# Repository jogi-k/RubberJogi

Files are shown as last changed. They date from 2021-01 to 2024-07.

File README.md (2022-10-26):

# 	RubberJogi

## What is the idea / the usecase ?

* You want to control a PC from another PC, making keystrokes, eventually mouse-moves.
* Even when starting up and e.g. entering the BIOS 
* => ssh etc not an option
* you need to be independent from any "client" on the controlled machine
* only solution which comes to mind is : USB HID
* Therefore you connect from PC I somehow to PC II, on PC II as USB-Keyboard

## Solution : RubberJogi

    +----------------+                                  +----------------+
    |                |                                  |                |
    |    PC I        |                                  |    PC II       |
    |                |          +-------------+         |                |
    |  (Controller)  | USB      |             |  USB    |  (Worker)      |
    |                +--------->+ RubberJogi  +-------->+                |
    |                | serial   |             |  HID    |                |
    |                |          +-------------+         |                |
    |                |                                  |                |
    +----------------+                                  +----------------+

* PC I connects to RubberJogi via USB-Serial
* RubberJogi injects Keystrokes etc via USB HID to PC II 

## Ingredients Hardware

* Arduino ( with USB-Keyboard capability), e.g. Leonardo, Micro, etc

* USB-TTL UART Converter , FTDI Serial

* some cables

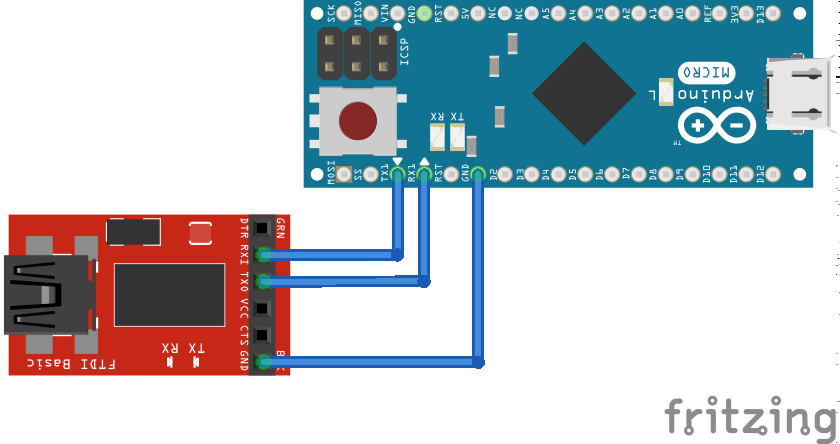
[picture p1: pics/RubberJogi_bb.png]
RubberJogi_bb
  

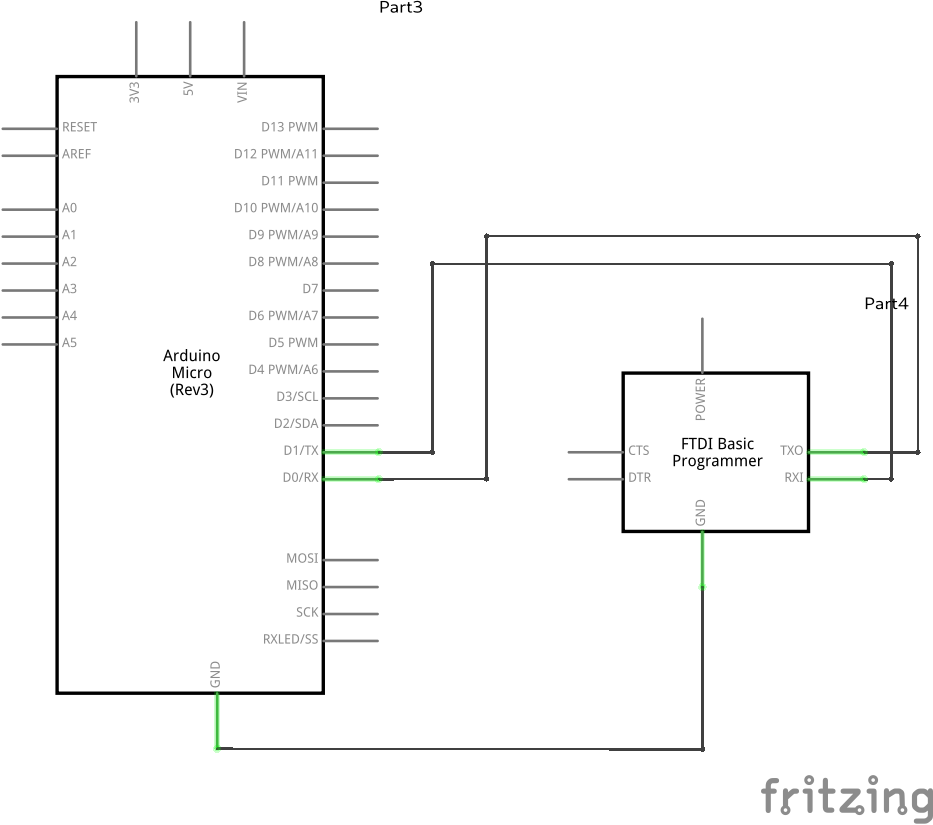
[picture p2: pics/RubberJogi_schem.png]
RubberJogi_schem
  

## Ingredients Software 

* As it is not possible to send CMD-Keys like ALT, CTRL via serial line, a language has to be used.
* Avoid to reinvent the wheel ==> Compatible to the famous [**RubberDucky**-Script-Language](https://github.com/hak5darren/USB-Rubber-Ducky/wiki/Duckyscript)
* ==> Based on arducky by Baptiste MOINE (Creased), THANKS!
* Parser is based on https://github.com/Creased/arducky/blob/master/arducky.ino
* is partially extended for also sending MOUSE-Movements
* is already extended to control four additional GPIO-Switches 
* Accepted Commands :
    * All RubberDucky-Commands (not really all...)
    * ```backspace```
    * ```switch1_on``` / ```switch1_off```  => switching Optocoupler at Pin2 
    * ```switch2_on``` / ```switch2_off```  => switching Optocoupler at Pin4 
    * ```switch3_on``` / ```switch3_off```  => switching Optocoupler at Pin6 
    * ```switch4_on``` / ```switch4_off```  => switching Optocoupler at Pin8
    * ```boot``` => switching Optocoupler at Pin2 for 1.5 sec high, then low
    * ```reboot``` => switching Optocoupler at Pin2 for 10sec high, then low, after a delay of 2 secs then once more for 1.5 sec high, then low
    * ```aten``` => switching Optocoupler at Pin4 for 1.5 sec high, then low

### Controlling 

For "talking" to the RubberJogi from PC1 you need to configure your serial port to

* 9600 Baud
* 8 Bit, 1 Stop-Bit, No parity

If you are using a linux-box you could use the follwing command to achieve this:   

```stty -F /dev/ttyUSB0 cs8 9600 ignbrk -brkint -icrnl -imaxbel -opost -onlcr -isig -icanon -iexten -echo -echoe -echok -echoctl -echoke noflsh -ixon -crtscts```  
Then you can just try out the functionality of the box with e.g :

* ```echo "ENTER" > /dev/ttyUSB0``` when you are allowed to use /dev/ttyUSB, or
* ```echo "ENTER" | sudo tee /dev/ttyUSB0``` when you need to be root to use /dev/ttyUSB

In both cases you should see a moving text-cursor on the second PC (best open an Editor...)

## Special Hardware with 2 switches

* In our/my usecase we also need to control two switches

* one of these is connected to the reset-button of the PC

* the other one is connected to the switch of a USB-sharing station, so we can switch a USB-stick between PC1 and PC2 ...

* more explanations will follow, the code is already able to make use of these 

* here at least are the schematics

* In case you want (like we do) to switch on PC2 with a command from PC1 you need to connect Vcc between FTDI and Arduino, otherwise the Arduino will not have power when he is connected to a switched of PC ... ( see the green cable below)
* Unfortunately, it looks like this is backfeeding 5V even to the 2nd PC via USB. This is not a problem if the PC is switched on. __BUT__ : If you have the PC switched off and want to switch it on, then - depending on the PC - it might make some trouble for the PC, as it is never __really__ switching completely off. I need to try this remedy : https://forum.arduino.cc/t/powering-the-arduino-with-a-5v-power-supply/261902/12   

* We tried out this remedy (remove T1 of the ARDUINO) and it works perfect. __BUT beware:__ when you want to re-programm the Arduino you __NEED__ to have the FTDI connected as well to a PC, as otherwise the Arduino is not powered...
* See here the location of the T1 to be removed: 
![Arduino T1 to be removed](pics/Arduino_T1_to_remove.png)

  ![RubberJogi_with_switch_bb](pics/RubberJogi_with_switch_bb.png)

  ![RubberJogi_with_switch_schem](pics/RubberJogi_with_switch_schem.png)

## Extended Special Hardware with 4 switches

  - in the meantime we even have use-cases where we need to control up to 4 switches

  - as before one of these is connected to the reset-button of the PC (in our case)

  - as before one is connected to the switch of a USB-sharing station, so we can switch a USB-stick between PC1 and PC2 ... (in our case)

  - the other 2 switches are needed to control boot-sel switches of embedded ARM systems  

  - here are the additional schematics

  - In case you want (like we do) to switch on PC2 with a command from PC1 you need to connect Vcc between FTDI and Arduino, otherwise the Arduino will not have power when he is connected to a switched of PC ... ( see the green cable below)
  - backfeeding 5V via USB to PC2: see above at the 2-Switch-Solution)

    ![RubberJogi_with_switch_bb](pics/RubberJogi_with_4_switches_bb.png)

    ![RubberJogi_with_switch_schem](pics/RubberJogi_with_4_switches_schem.png)

## Extended Special Hardware with 5 switches and one relay

- finally (in our application) we need to switch power 
- we introduced a 5th optocoupler, connected to pin10 AND we connected a real relay to that to be able to switch power
- schematics will follow

## Reality

This is one sample-prototype without any switches, just the "plain" RubberJogi. This was soldered "flying" and is only stabilized with heat shrink tube.

![RubberJogi_with_4_switches_sample](pics/RubberJogi_Aufbau_NoSwitch.jpg)

This is one sample-prototype, with 4 switches, soldered on a veroboard/breadboard

![RubberJogi_with_4_switches_sample](pics/RubberJogi_Aufbau.jpg)

These are all 3 prototypes I have built, together on one picture. 

* 2 times extended RubberJogis with 4 switches
* 1 as a pure RubberJogi, no switches.

![Different RubberJogis](pics/RubberJogi_all.jpg)

## Parts-List

What do you need to build a RubberJogi?

| Part                                                  | Rubber<br> Jogi<br> Standard | Rubber <br> Jogi<br>Two Switch | Rubber <br> Jogi<br>Four Switch |
| ----------------------------------------------------- | ---------------------------- | ------------------------------ | ------------------------------- |
| Arduino Micro                                         | 1                            | 1                              | 1                               |
| FTDI USB / Serial Converter 5V capable                | 1                            | 1                              | 1                               |
| Cables between Arduino/FTDI<br>(Vcc, GND, RxD, TxD)   | 4                            | 4                              | 4                               |
| USB-Cable to Arduino <br />(USB-A to Micro-USB)       | 1                            | 1                              | 1                               |
| USB-Cable to FTDI<br>(USB-A to Mini-USB)              | 1                            | 1                              | 1                               |
| Veroboard                                             | ?                            | ca 60x50 mm                    | ca 60x50mm                      |
| Header Arduino<br>(when not using already w/ headers) | ?                            | 34                             | 34                              |
| Header FTDI                                           | ?                            | 18                             | 18                              |
| Optocoupler 4N25 DIL                                  | 0                            | 2                              | 4                               |
| Resistor 390 Ohm                                      | 0                            | 2                              | 4                               |
| Connectors, depends on your needs, e.g                | 0                            | 2                              | 4                               |
| **Example**: Headers for switches                     | 0                            | 4                              | 8                               |

## Links, Ideas

* Mouse-Support currently missing to 90%, positioning does not work. Maybe move to USB-Touch-Screen could solve the problem? Please have a look at this project, might be worth checking out : https://github.com/NicoHood/HID
* Another potential usefull link to solve the mouse-move would be  : https://www.codeproject.com/Articles/1001891/A-USB-HID-Keyboard-Mouse-Touchscreen-emulator-with

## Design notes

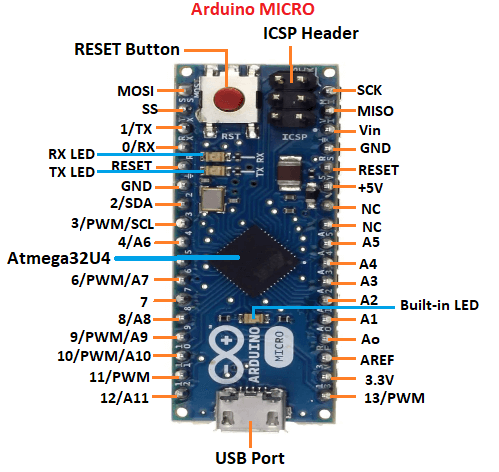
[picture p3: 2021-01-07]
arduino-micro-pinout.png

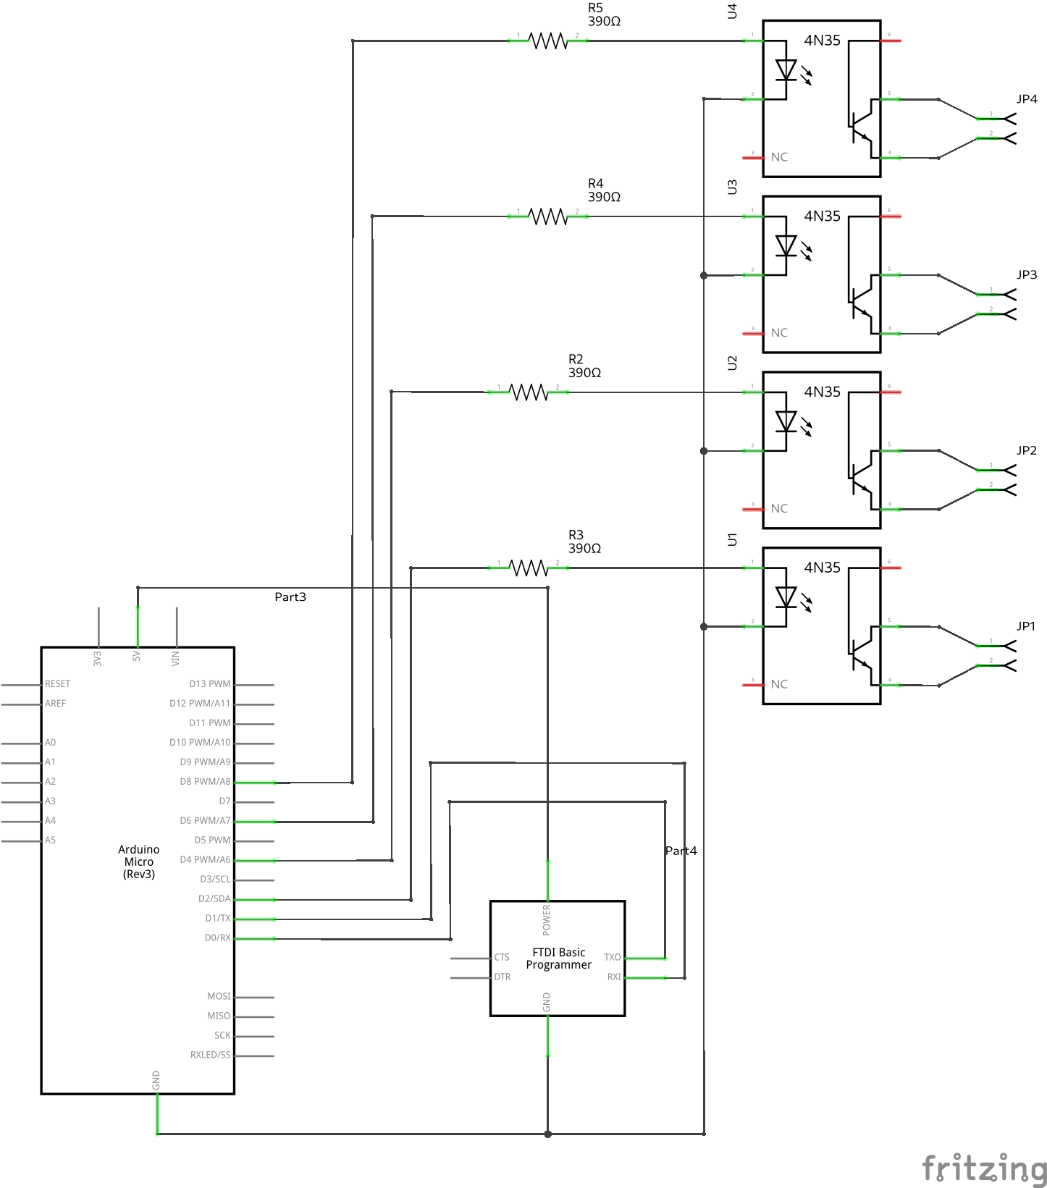
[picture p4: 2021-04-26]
pics/RubberJogi_with_4_switches_schem.png

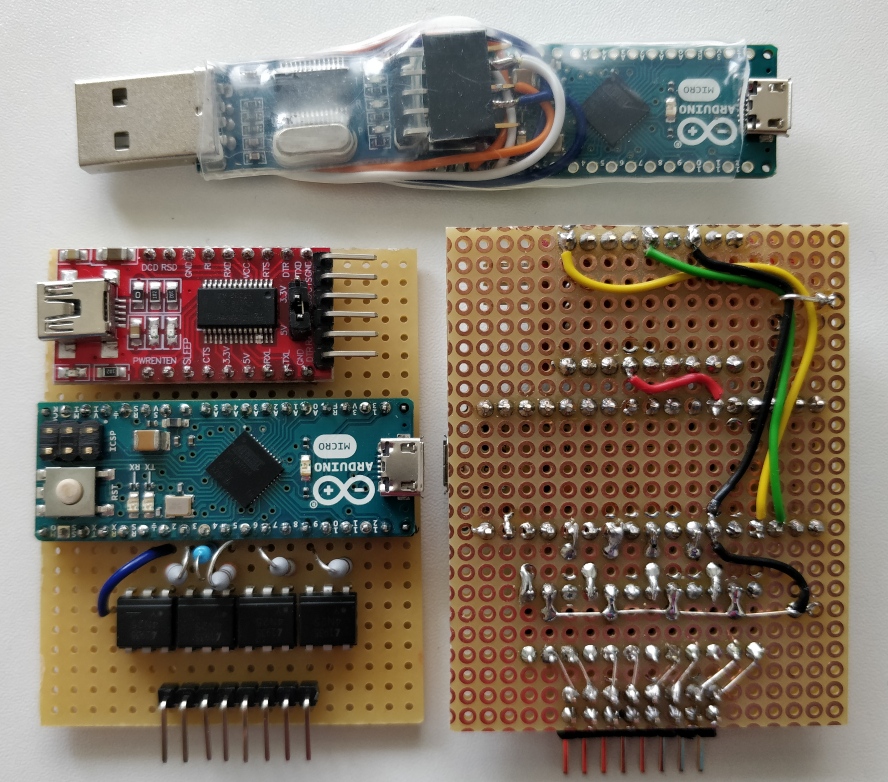
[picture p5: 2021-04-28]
pics/RubberJogi_all.jpg

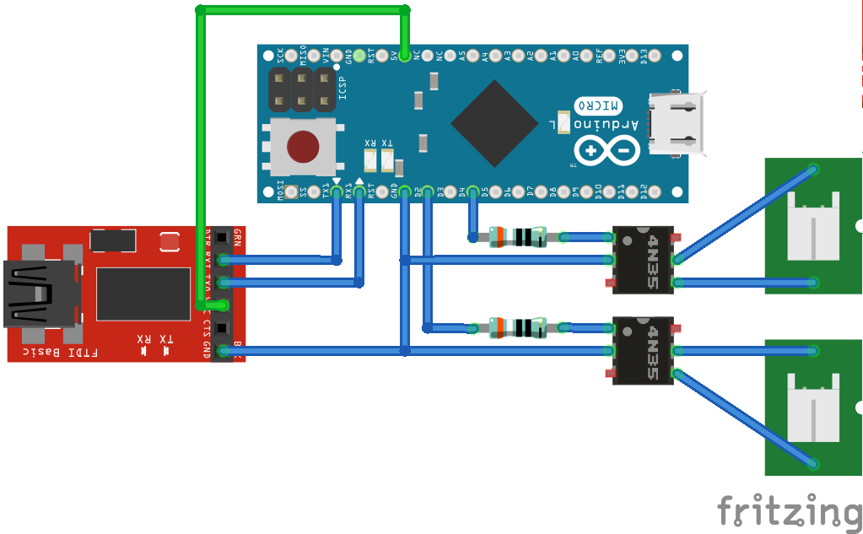
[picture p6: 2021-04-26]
pics/RubberJogi_with_switch_bb.png

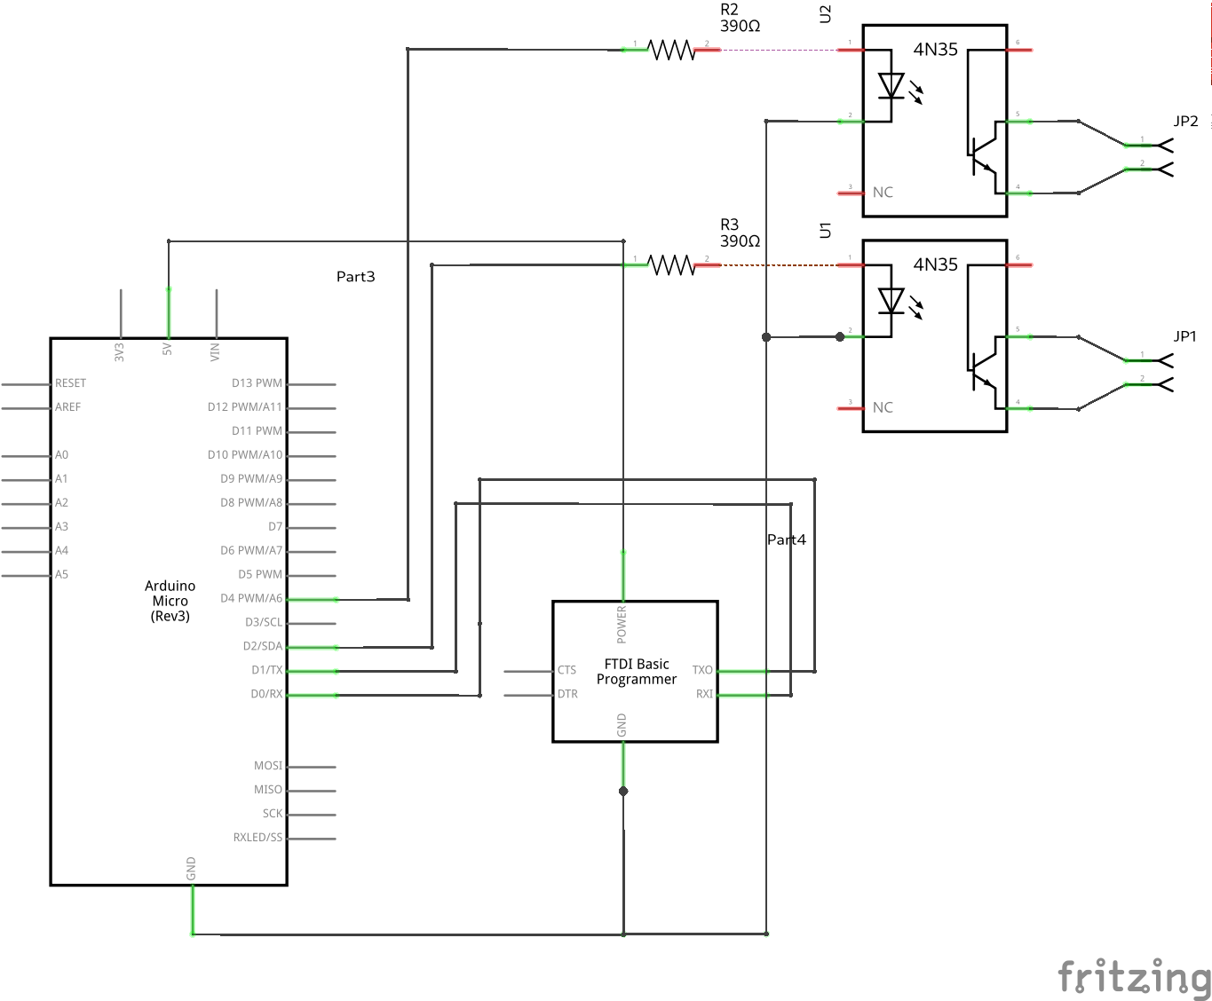
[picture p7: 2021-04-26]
pics/RubberJogi_with_switch_schem.png

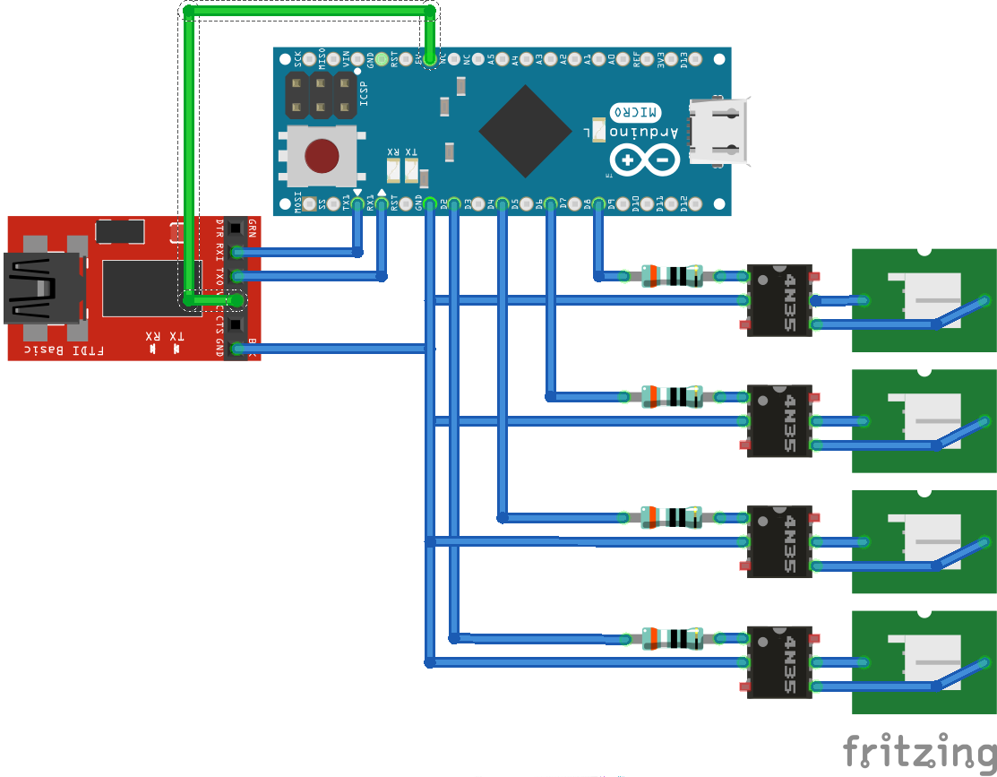
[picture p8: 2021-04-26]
pics/RubberJogi_with_4_switches_bb.png

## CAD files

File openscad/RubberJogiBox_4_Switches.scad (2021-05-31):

$fn=100;




translate([-w/2-10,0,d+bpt+tpt])
rotate(a=180, v=[0,1,0])
box_top();
translate([w/2+10,0,0])
box_bottom();
             

//*************************************************//
//PARAMETERS
//*************************************************//
//BOX
//--------------------------------------------------
//inner box width + tolerances
w=80;
//inner box length + tolerances
h=50;
//inner box depth 
d=20;
//wall tickness
wt=3;
//bottom plate tickness
bpt=3;
//top plate tickness
tpt=3;
//top cutout depth
cd=3;
//top cutout tickness
cwt=1.5;
//--------------------------------------------------
//BOARD MOUNTING HOLES
//--------------------------------------------------
//position
cx=0;
cy=0;
//holes size (radius)
chs_i=1.5;
chs_o=4;
//distancer height
dsth=3;
//holes distance h
chd_h=65;
//holes distance v
chd_v=35;
//--------------------------------------------------
//TOP PART MOUNTING HOLES
//--------------------------------------------------
//position
cx1=0;
cy1=0;
//holes size (radius)
chs_i1=1.6;
chs_o1=3;
//holes distance h
chd_h1=h-2*chs_i1-2;
//holes distance v
chd_v1=w-2*chs_i1-2;
//*************************************************//
//*************************************************//
//MODULES
//*************************************************//

//top box part          
module box_top()
{
        difference()
        {
            union()
            {
                difference()
                {
                    translate([ 0, 0, d+bpt-cd-0.2])     
                    rounded_cube( w+2*wt, h+2*wt, tpt+cd+0.2, 6);
                    
                    translate([ 0, 0,  d+bpt-cd-1])
                    rounded_cube( w+2*cwt+0.3, h+2*cwt+0.3, cd+1, 4);
                }
                /*************************/
                
                //add here...
                
                /*************************/
            }
            //TOP PART HOLES
            tph_t_cut();
            /*************************/
            
            //subtract here... 
            
            /*************************/ 
        }
}
//bottom box
module box_bottom()
{
    difference()
    {
        union()
        {
            difference()
            {
                rounded_cube( w+2*wt, h+2*wt, d+bpt, 6);
                
                translate([ 0, 0, -cd])
                difference()
                {
                    translate([ 0, 0,  d+bpt])
                    rounded_cube( w+2*wt+1, h+2*wt+1, cd+1, 4);

                    translate([ 0, 0,  d+bpt-1])
                    rounded_cube( w+2*cwt, h+2*cwt, cd+3, 4);
                }
                translate([ 0, 0, bpt])
                rounded_cube( w, h, d+bpt, 4);
            }
            //BOARD DISTANCER
            board_distancer();
            //TOP PLATE DISTANCER
            top_distancer();
            /*************************/
            
            //add here...
            
            /*************************/
        }
        
        //BOARD HOLES
        bh_cut();
        //TOP PART HOLES
        tph_b_cut();
        /*************************/
        
        //subtract here...
        
        /*************************/
  
    }
}

/****************************************************/
module board_distancer()
{
    translate([cx,cy,0])
    {              
        translate([+chd_h/2,chd_v/2,0])
        cylinder(r=chs_o,h=bpt+dsth);
        translate([-chd_h/2,chd_v/2,0])
        cylinder(r=chs_o,h=bpt+dsth);
        translate([+chd_h/2,-chd_v/2,0])
        cylinder(r=chs_o,h=bpt+dsth);
        translate([-chd_h/2,-chd_v/2,0])
        cylinder(r=chs_o,h=bpt+dsth);
    }
}
module top_distancer()
{
    translate([cx1,cy1,0])
    {
        translate([-chd_v1/2, chd_h1/2, 0])   
        cylinder(r=chs_o1,h=d+bpt);
        translate([-chd_v1/2, -chd_h1/2, 0])   
        cylinder(r=chs_o1,h=d+bpt);
        translate([chd_v1/2, chd_h1/2, 0])   
        cylinder(r=chs_o1,h=d+bpt);
        translate([chd_v1/2, -chd_h1/2, 0])   
        cylinder(r=chs_o1,h=d+bpt);
    }
}
module bh_cut()
{
    translate([cx,cy,0])
    {  
        translate([-chd_h/2,-chd_v/2,-1])
        cylinder(r=chs_i,h=bpt+dsth+2);
        translate([+chd_h/2,-chd_v/2,-1])
        cylinder(r=chs_i,h=bpt+dsth+2);
        translate([-chd_h/2,chd_v/2,-1])
        cylinder(r=chs_i,h=bpt+dsth+2);
        translate([+chd_h/2,chd_v/2,-1])
        cylinder(r=chs_i,h=bpt+dsth+2);
        
        translate([-chd_h/2,-chd_v/2,1.3])
        fhex(5.5,3);
        translate([+chd_h/2,-chd_v/2,1.3])
        fhex(5.5,3);
        translate([-chd_h/2,chd_v/2,1.3])
        fhex(5.5,3);
        translate([+chd_h/2,chd_v/2,1.3])
        fhex(5.5,3);
    }
}

module tph_t_cut()
{
    translate([cx1,cy1,0])
    {
        translate([-chd_v1/2, chd_h1/2, -2])   
        cylinder(r=chs_i1,h=d+bpt+tpt+3);
        translate([chd_v1/2, chd_h1/2, -2])   
        cylinder(r=chs_i1,h=d+bpt+tpt+3);
    
        translate([-chd_v1/2, -chd_h1/2, -2])   
        cylinder(r=chs_i1,h=d+bpt+tpt+3);
        translate([chd_v1/2, -chd_h1/2, -2])   
        cylinder(r=chs_i1,h=d+bpt+tpt+3);
        
        translate([-chd_v1/2, chd_h1/2, d+bpt+tpt-1.3]) 
        fhex(5.5,3);
        
        translate([chd_v1/2, chd_h1/2, d+bpt+tpt-1.3])  
        fhex(5.5,3);
    
        translate([-chd_v1/2, -chd_h1/2, d+bpt+tpt-1.3])   
        fhex(5.5,3);
        
        translate([chd_v1/2, -chd_h1/2, d+bpt+tpt-1.3])   
        fhex(5.5,3);
    
    }   
}
module tph_b_cut()
{
    translate([cx1,cy1,0])
    {
        translate([-chd_v1/2, chd_h1/2, -2])   
        cylinder(r=chs_i1,h=d+bpt+3);
        translate([chd_v1/2, chd_h1/2, -2])   
        cylinder(r=chs_i1,h=d+bpt+3);
    
        translate([-chd_v1/2, -chd_h1/2, -2])   
        cylinder(r=chs_i1,h=d+bpt+3);
        translate([chd_v1/2, -chd_h1/2, -2])   
        cylinder(r=chs_i1,h=d+bpt+3);
        
        translate([-chd_v1/2, chd_h1/2, -1]) 
        cylinder(r=3,h=4);
        
        translate([chd_v1/2, chd_h1/2, -1])  
        cylinder(r=3,h=4);
    
        translate([-chd_v1/2, -chd_h1/2, -1])   
        cylinder(r=3,h=4);
        
        translate([chd_v1/2, -chd_h1/2, -1])   
        cylinder(r=3,h=4); 
    
    }   
}


module rounded_cube( x, y, z, r)
{
    translate([-x/2+r,-y/2+r,0])
    linear_extrude(height=z)
    minkowski() 
    {
        square([x-2*r,y-2*r],true);
        translate([x/2-r,y/2-r,0])
        circle(r);

    }
}

module fhex(wid,height)
{
    hull()
    {
        cube([wid/1.7,wid,height],center = true);
        rotate([0,0,120])cube([wid/1.7,wid,height],center = true);
        rotate([0,0,240])cube([wid/1.7,wid,height],center = true);
    }
}

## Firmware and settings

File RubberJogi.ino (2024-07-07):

// RubberJogi
// ==========
//
// Use it like its name-patron the RubberDucky, but:
// Instead of reading the RubberDucky-Script from SD-card, RubberJogi receives
// its commands from the Controller-PC
//
// Receives Data on the serial1 (NOT USB-serial), parses it according to
// RubberDucky-Language-definition and "executes" then on the USB-HID , keyboard
// and mouse. Use together with an USB TTL UART - connector to control a PC with
// a simulated keyboard.
//
// Thanks very much to Baptiste M. (Creased) , who created arducky (
// https://github.com/Creased/arducky ) from where I have taken 90% of the base
// of this tool,

#include "RubberJogi.h"

RubberJogi rj;

void setup() { rj.printVersion(); }

void loop() {
  if (rj.readCommand()) {
    rj.parseCommand();
  }
}

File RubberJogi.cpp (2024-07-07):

#include "RubberJogi.h"

#include "Keys.h"

namespace {
enum MouseButtons : uint8_t {
  LEFT = 1,
  RIGHT = 2,
  MIDDLE = 4,
};

bool isKeyboardCommand(String cmd) {
  cmd.toUpperCase();
  return cmd == "ENTER" || cmd == "DOWNARROW" || cmd == "DOWN" ||
         cmd == "LEFTARROW" || cmd == "LEFT" || cmd == "RIGHTARROW" ||
         cmd == "RIGHT" || cmd == "UPARROW" || cmd == "UP" || cmd == "DELETE" ||
         cmd == "DEL" || cmd == "END" || cmd == "ESC" || cmd == "ESCAPE" ||
         cmd == "HOME" || cmd == "INSERT" || cmd == "PAGEUP" ||
         cmd == "PAGEDOWN" || cmd == "PRINTSCREEN" || cmd == "SPACE" ||
         cmd == "TAB" || cmd == "F1" || cmd == "F2" || cmd == "F3" ||
         cmd == "F4" || cmd == "F5" || cmd == "F6" || cmd == "F7" ||
         cmd == "F8" || cmd == "F9" || cmd == "F10" || cmd == "F11" ||
         cmd == "F12" || cmd == "FUNCTION1" || cmd == "FUNCTION2" ||
         cmd == "FUNCTION3" || cmd == "FUNCTION4" || cmd == "FUNCTION5" ||
         cmd == "FUNCTION6" || cmd == "FUNCTION7" || cmd == "FUNCTION8" ||
         cmd == "FUNCTION9" || cmd == "FUNCTION10" || cmd == "FUNCTION11" ||
         cmd == "FUNCTION12" || cmd == "BACKSPACE" || cmd == "CAPSLOCK" ||
         cmd == "SCROLLLOCK" || cmd == "NUMLOCK" || cmd == "MENU" ||
         cmd == "APP" || cmd == "PAUSE" || cmd == "BREAK" ||
         cmd.startsWith("SHIFT") || cmd.startsWith("ALT") ||
         cmd.startsWith("CTRL") || cmd.startsWith("CONTROL") ||
         cmd.startsWith("GUI") || cmd.startsWith("WINDOWS") ||
         cmd.startsWith("STRING ") || cmd.startsWith("INJECT_MOD ");
}

bool isMouseCommand(const String &cmd) {
  return cmd.substring(0, 5).equalsIgnoreCase("MOUSE");
}

bool isSwitchCommand(String cmd) {
  cmd.toUpperCase();
  return cmd.startsWith("SWITCH") || cmd == "BOOT" || cmd == "REBOOT" ||
         cmd == "ATEN";
}

bool isDelayCommand(const String &cmd) {
  return cmd.substring(0, 5).equalsIgnoreCase("DELAY");
}

bool isComment(const String &cmd) { return cmd.equalsIgnoreCase("REM"); }

uint8_t getKeyCode(const String &key) {
  if (key.length() == 1) {
    return key[0];
  } else if (key.equalsIgnoreCase("ENTER")) {
    return KEY_RETURN;
  } else if (key.equalsIgnoreCase("MENU") || key.equalsIgnoreCase("APP")) {
    return KEY_MENU;
  } else if (key.equalsIgnoreCase("DOWNARROW") ||
             key.equalsIgnoreCase("DOWN")) {
    return KEY_DOWN_ARROW;
  } else if (key.equalsIgnoreCase("LEFTARROW") ||
             key.equalsIgnoreCase("LEFT")) {
    return KEY_LEFT_ARROW;
  } else if (key.equalsIgnoreCase("RIGHTARROW") ||
             key.equalsIgnoreCase("RIGHT")) {
    return KEY_RIGHT_ARROW;
  } else if (key.equalsIgnoreCase("UPARROW") || key.equalsIgnoreCase("UP")) {
    return KEY_UP_ARROW;
  } else if (key.equalsIgnoreCase("PAUSE") || key.equalsIgnoreCase("BREAK")) {
    return KEY_PAUSE;
  } else if (key.equalsIgnoreCase("CAPSLOCK")) {
    return KEY_CAPS_LOCK;
  } else if (key.equalsIgnoreCase("DELETE") || key.equalsIgnoreCase("DEL")) {
    return KEY_DELETE;
  } else if (key.equalsIgnoreCase("END")) {
    return KEY_END;
  } else if (key.equalsIgnoreCase("ESC") || key.equalsIgnoreCase("ESCAPE")) {
    return KEY_ESC;
  } else if (key.equalsIgnoreCase("HOME")) {
    return KEY_HOME;
  } else if (key.equalsIgnoreCase("INSERT")) {
    return KEY_INSERT;
  } else if (key.equalsIgnoreCase("NUMLOCK")) {
    return KEY_NUM_LOCK;
  } else if (key.equalsIgnoreCase("PAGEUP")) {
    return KEY_PAGE_UP;
  } else if (key.equalsIgnoreCase("PAGEDOWN")) {
    return KEY_PAGE_DOWN;
  } else if (key.equalsIgnoreCase("PRINTSCREEN")) {
    return KEY_PRINT_SCREEN;
  } else if (key.equalsIgnoreCase("SCROLLLOCK")) {
    return KEY_SCROLL_LOCK;
  } else if (key.equalsIgnoreCase("SPACE")) {
    return KEY_SPACE;
  } else if (key.equalsIgnoreCase("BACKSPACE")) {
    return KEY_BACKSPACE;
  } else if (key.equalsIgnoreCase("TAB")) {
    return KEY_TAB;
  } else if (key.equalsIgnoreCase("GUI") || key.equalsIgnoreCase("WINDOWS")) {
    return KEY_LEFT_GUI;
  } else if (key.equalsIgnoreCase("SHIFT")) {
    return KEY_RIGHT_SHIFT;
  } else if (key.equalsIgnoreCase("ALT")) {
    return KEY_LEFT_ALT;
  } else if (key.equalsIgnoreCase("CTRL") || key.equalsIgnoreCase("CONTROL")) {
    return KEY_LEFT_CTRL;
  } else if (key.equalsIgnoreCase("F1") || key.equalsIgnoreCase("FUNCTION1")) {
    return KEY_F1;
  } else if (key.equalsIgnoreCase("F2") || key.equalsIgnoreCase("FUNCTION2")) {
    return KEY_F2;
  } else if (key.equalsIgnoreCase("F3") || key.equalsIgnoreCase("FUNCTION3")) {
    return KEY_F3;
  } else if (key.equalsIgnoreCase("F4") || key.equalsIgnoreCase("FUNCTION4")) {
    return KEY_F4;
  } else if (key.equalsIgnoreCase("F5") || key.equalsIgnoreCase("FUNCTION5")) {
    return KEY_F5;
  } else if (key.equalsIgnoreCase("F6") || key.equalsIgnoreCase("FUNCTION6")) {
    return KEY_F6;
  } else if (key.equalsIgnoreCase("F7") || key.equalsIgnoreCase("FUNCTION7")) {
    return KEY_F7;
  } else if (key.equalsIgnoreCase("F8") || key.equalsIgnoreCase("FUNCTION8")) {
    return KEY_F8;
  } else if (key.equalsIgnoreCase("F9") || key.equalsIgnoreCase("FUNCTION9")) {
    return KEY_F9;
  } else if (key.equalsIgnoreCase("F10") ||
             key.equalsIgnoreCase("FUNCTION10")) {
    return KEY_F10;
  } else if (key.equalsIgnoreCase("F11") ||
             key.equalsIgnoreCase("FUNCTION11")) {
    return KEY_F11;
  } else if (key.equalsIgnoreCase("F12") ||
             key.equalsIgnoreCase("FUNCTION12")) {
    return KEY_F12;
  }

  return -1;
}

bool isModifierKey(uint8_t key) {
  switch (key) {
  case KEY_LEFT_SHIFT:
  case KEY_RIGHT_SHIFT:
  case KEY_LEFT_ALT:
  case KEY_RIGHT_ALT:
  case KEY_LEFT_CTRL:
  case KEY_RIGHT_CTRL:
  case KEY_LEFT_GUI:
  case KEY_RIGHT_GUI:
    return true;
  default:
    return false;
  }
}

} // namespace

RubberJogi::RubberJogi()
    : PluggableUSBModule(NUM_INTERFACES, NUM_ENDPOINTS, _epType) {
  Serial1.begin(9600);

  _buffer.reserve(100);

  static_assert(MOUSE_OFFSET < NUM_ENDPOINTS);

  _epType[KEYBOARD_OFFSET] = EP_TYPE_INTERRUPT_IN;
  _epType[MOUSE_OFFSET] = EP_TYPE_INTERRUPT_IN;

  PluggableUSB().plug(this);

  _initSwitches();
}

void RubberJogi::printVersion() const {
  Serial1.println(VERSION);
  Serial1.println("w BOOT/ATEN/SWITCH-Support");
}

void RubberJogi::setKeyboardLayout(const uint8_t *layout) { _layout = layout; }

bool RubberJogi::readCommand() {
  while (Serial1.available()) {
    char c = Serial1.read();

    // CR and LF terminate commands and are not added to the buffer
    // Don't report a new command being available if the buffer is empty
    if (c == '\r' || c == '\n') {
      if (_buffer.length() > 0) {
        Serial1.println(String("Received: ") + _buffer);
        return true;
      } else {
        continue;
      }
    }

    _buffer += c;
  }

  return false;
}

const String &RubberJogi::getCommand() const { return _buffer; }
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

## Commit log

2021-01-16 Improved documentation, added fritzing-files and pictures
    [RubberJogi.fzz]
2021-01-16 Added the two switches via Opto-Coupler as fritzing and in the README
    [RubberJogi_with_switch.fzz]
2021-01-17 First Mouse-Movements and support for ATEN-Switch (hijacked MOUSE_CENTER...)
2021-01-19 Support for the two Optocoupler-Switches (only with old commands), Support for GUI without payload
2021-01-19 Updated HW-Layout etc for RubberJogi with Switches, Port 3 => Port 4
    [RubberJogi_with_switch.fzz]
2021-04-17 Prepare for 4 Switches
    [RubberJogi_with_4_switches.fzz]
2021-04-18 Add 4 Switch functionality, rename some strings to distinguish between original and new
2021-04-25 RubberJogi with 4 instead of 2 switches
    [RubberJogi_with_4_switches.fzz]
2021-04-25 New pictures and move fritzing-files to subdir
    [RubberJogi.fzz, RubberJogi_with_4_switches.fzz, RubberJogi_with_switch.fzz]
2021-04-26 Added photos, some clarifications, added Vcc - Line and explanation
    [RubberJogi_with_4_switches.fzz, RubberJogi_with_switch.fzz]
2021-04-28 Fixed backspace-problem, Fixes #2
    [RubberJogi.ino]
2021-05-03 Added simplest test-shellscript for the switches
2021-05-31 Box with OpenScad for RubberJogi with 4 switches
    [RubberJogiBox_4_Switches.scad]
2021-06-12 Problems documented with backfeeding power via USB
2021-07-16 Create test_switches.ps1 to test RubberJogi-Switches from Windows
2021-07-18 Added test_hid Powershell-Script for testing with Windows
2021-08-18 Updated hints about 5V-backfeeding to USB and programming the Arduino
2022-01-19 Picture of removal of T1 on Arduino added
2022-06-07 Added Switch Nr 5 for the new relais
2024-06-12 Refactoring to fix HID boot device support
    [HIDDescriptor.h, RubberJogi.cpp, RubberJogi.ino]
2024-07-05 Fix keys with space
    [RubberJogi.cpp]
